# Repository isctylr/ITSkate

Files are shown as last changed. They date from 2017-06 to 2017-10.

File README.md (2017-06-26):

# ITSkate
The collection of hardware and software for my electric skateboard project.

The only portion currently available is the remote, which can be found in the "Remote" folder.
  - This includes the hardware for the remote (TX), joystick, and receiver (RX), plus software. More information available in the folder.

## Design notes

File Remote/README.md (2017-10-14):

# ITSkate Remote

An open source remote for the VESC based on the arduino samd architecture and the HM-10 BLE module.

To build the board from scratch will require the following items:
	- All 3 finished boards (A BOM is in the works, but can be determined from the EAGLE files under "Hardware").
	- The Arduino IDE with the Arduino SAMD boards installed.
	- The bootloader, which can be loaded by adding http://isaactaylor.net/package_itaylor_index.json to Preferences>Additional Boards Manager URLs, and installing ITSkate Remote from the Board Manager.
	- A j-link, stlink v2, or other programmer for the samd chip. (This guide will use the stlink v2).

## Building the board

## Programming the HM-10s

Programming the HM-10 module takes 6 steps, using the AT commands. You may choose to perform this step later, as the TX software includes an AT passthrough mode.

You can learn more about the HM-10 and it's AT commands from the manual: http://fab.cba.mit.edu/classes/863.15/doc/tutorials/programming/bluetooth/bluetooth40_en.pdf

1. AT
You should recieve OK in return. If nothing appears, make sure you have a genuine HM10 and not a clone, then make sure you are not sending LF or CR, and that your baud rate is 9600 (we will be changing this later, but this is the default).

2. AT+ADDR?
Take note of the address of both the RX and TX.

3. AT+ROLE?
Setting the role will depend on if this is the TX or RX. The TX will be set to AT+ROLE1, because it is the master device. The RX will be set to AT+ROLE0 (left as default).

4. AT+CONxxxxxxxx
Replace the xxxxx with the address of the opposite board, performing the command first on the RX board, then the TX. If both are powered on, you should recieve OK+CONN from the TX.

5. AT+POWE3
Boost the power on both to 6dbm.

6. AT+BAUD4
Set the baud rate of the UART connection to 115200. 

7. AT+RESET
After resetting you'll have to reconnect with the baud rate of 115200. You can type AT to check your work.

## Building the bootloader

## Flashing the bootloader

## Loading the software

Download VescUartControl library by RollingGecko Make sure to choose the
VESC6 branch if you program your vesc with vesc-tool and not bldc.
Add the following lines to VescUart.h:

#ifdef ARDUINO_ARCH_SAMD
#define SERIALIO Serial1  
#define DEBUGSERIAL Serial
#endif

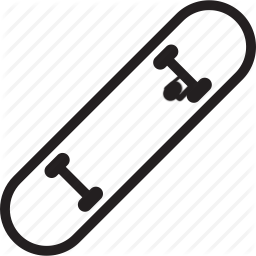
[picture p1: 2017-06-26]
Remote/hardware/skateboard-256.bmp

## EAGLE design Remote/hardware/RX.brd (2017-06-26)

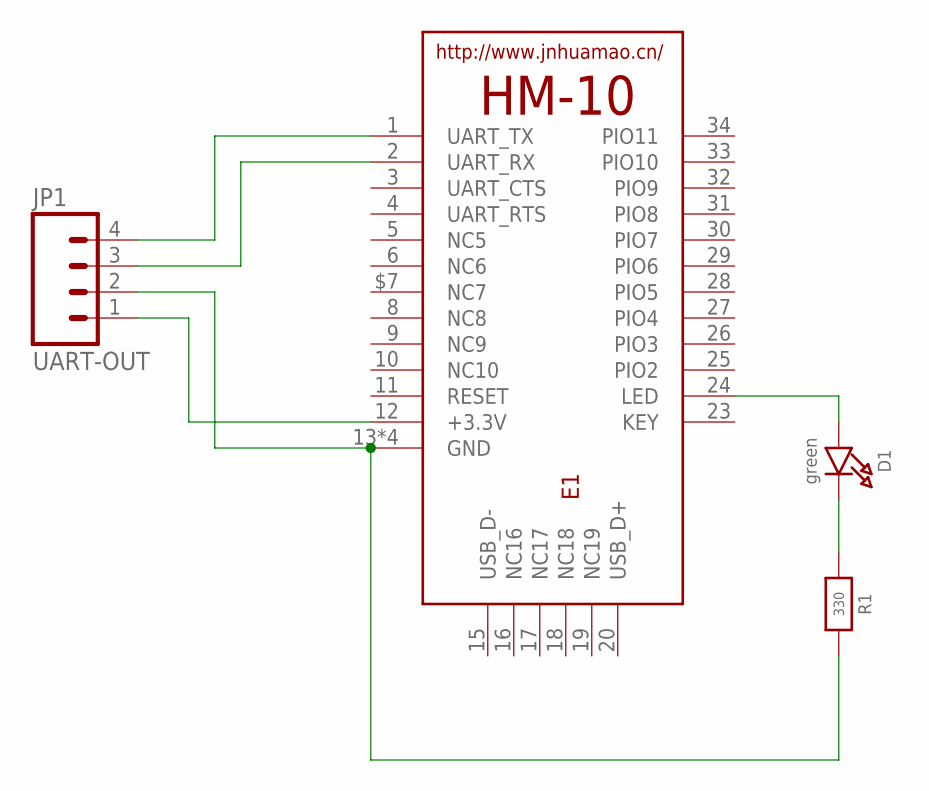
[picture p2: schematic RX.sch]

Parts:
D1: green; CHIPLED_0805_NOOUTLINE
E1: HM-10-BOARD; 26.9X13X2.2_BOARD
JP1: UART-OUT; 1X04
R1: 330; 0805-NO

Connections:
unnamed: E1.1 (UART_TX), JP1.4
unnamed: E1.2 (UART_RX), JP1.3
unnamed: E1.13 (GND), E1.14 (GND), E1.21 (GND), E1.22 (GND), JP1.2, R1.2
unnamed: E1.12 (+3.3V), JP1.1
unnamed: D1.A, E1.24 (LED)
unnamed: D1.C, R1.1

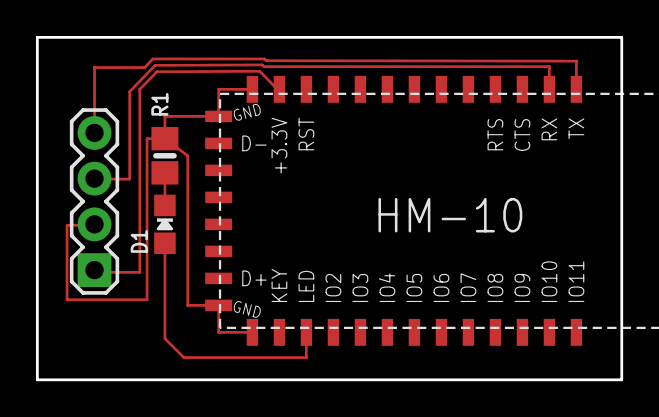
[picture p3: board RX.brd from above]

Board: 2 copper layers, 32.5 x 19.0 mm, 4 parts (0 on the bottom side), 6 nets.

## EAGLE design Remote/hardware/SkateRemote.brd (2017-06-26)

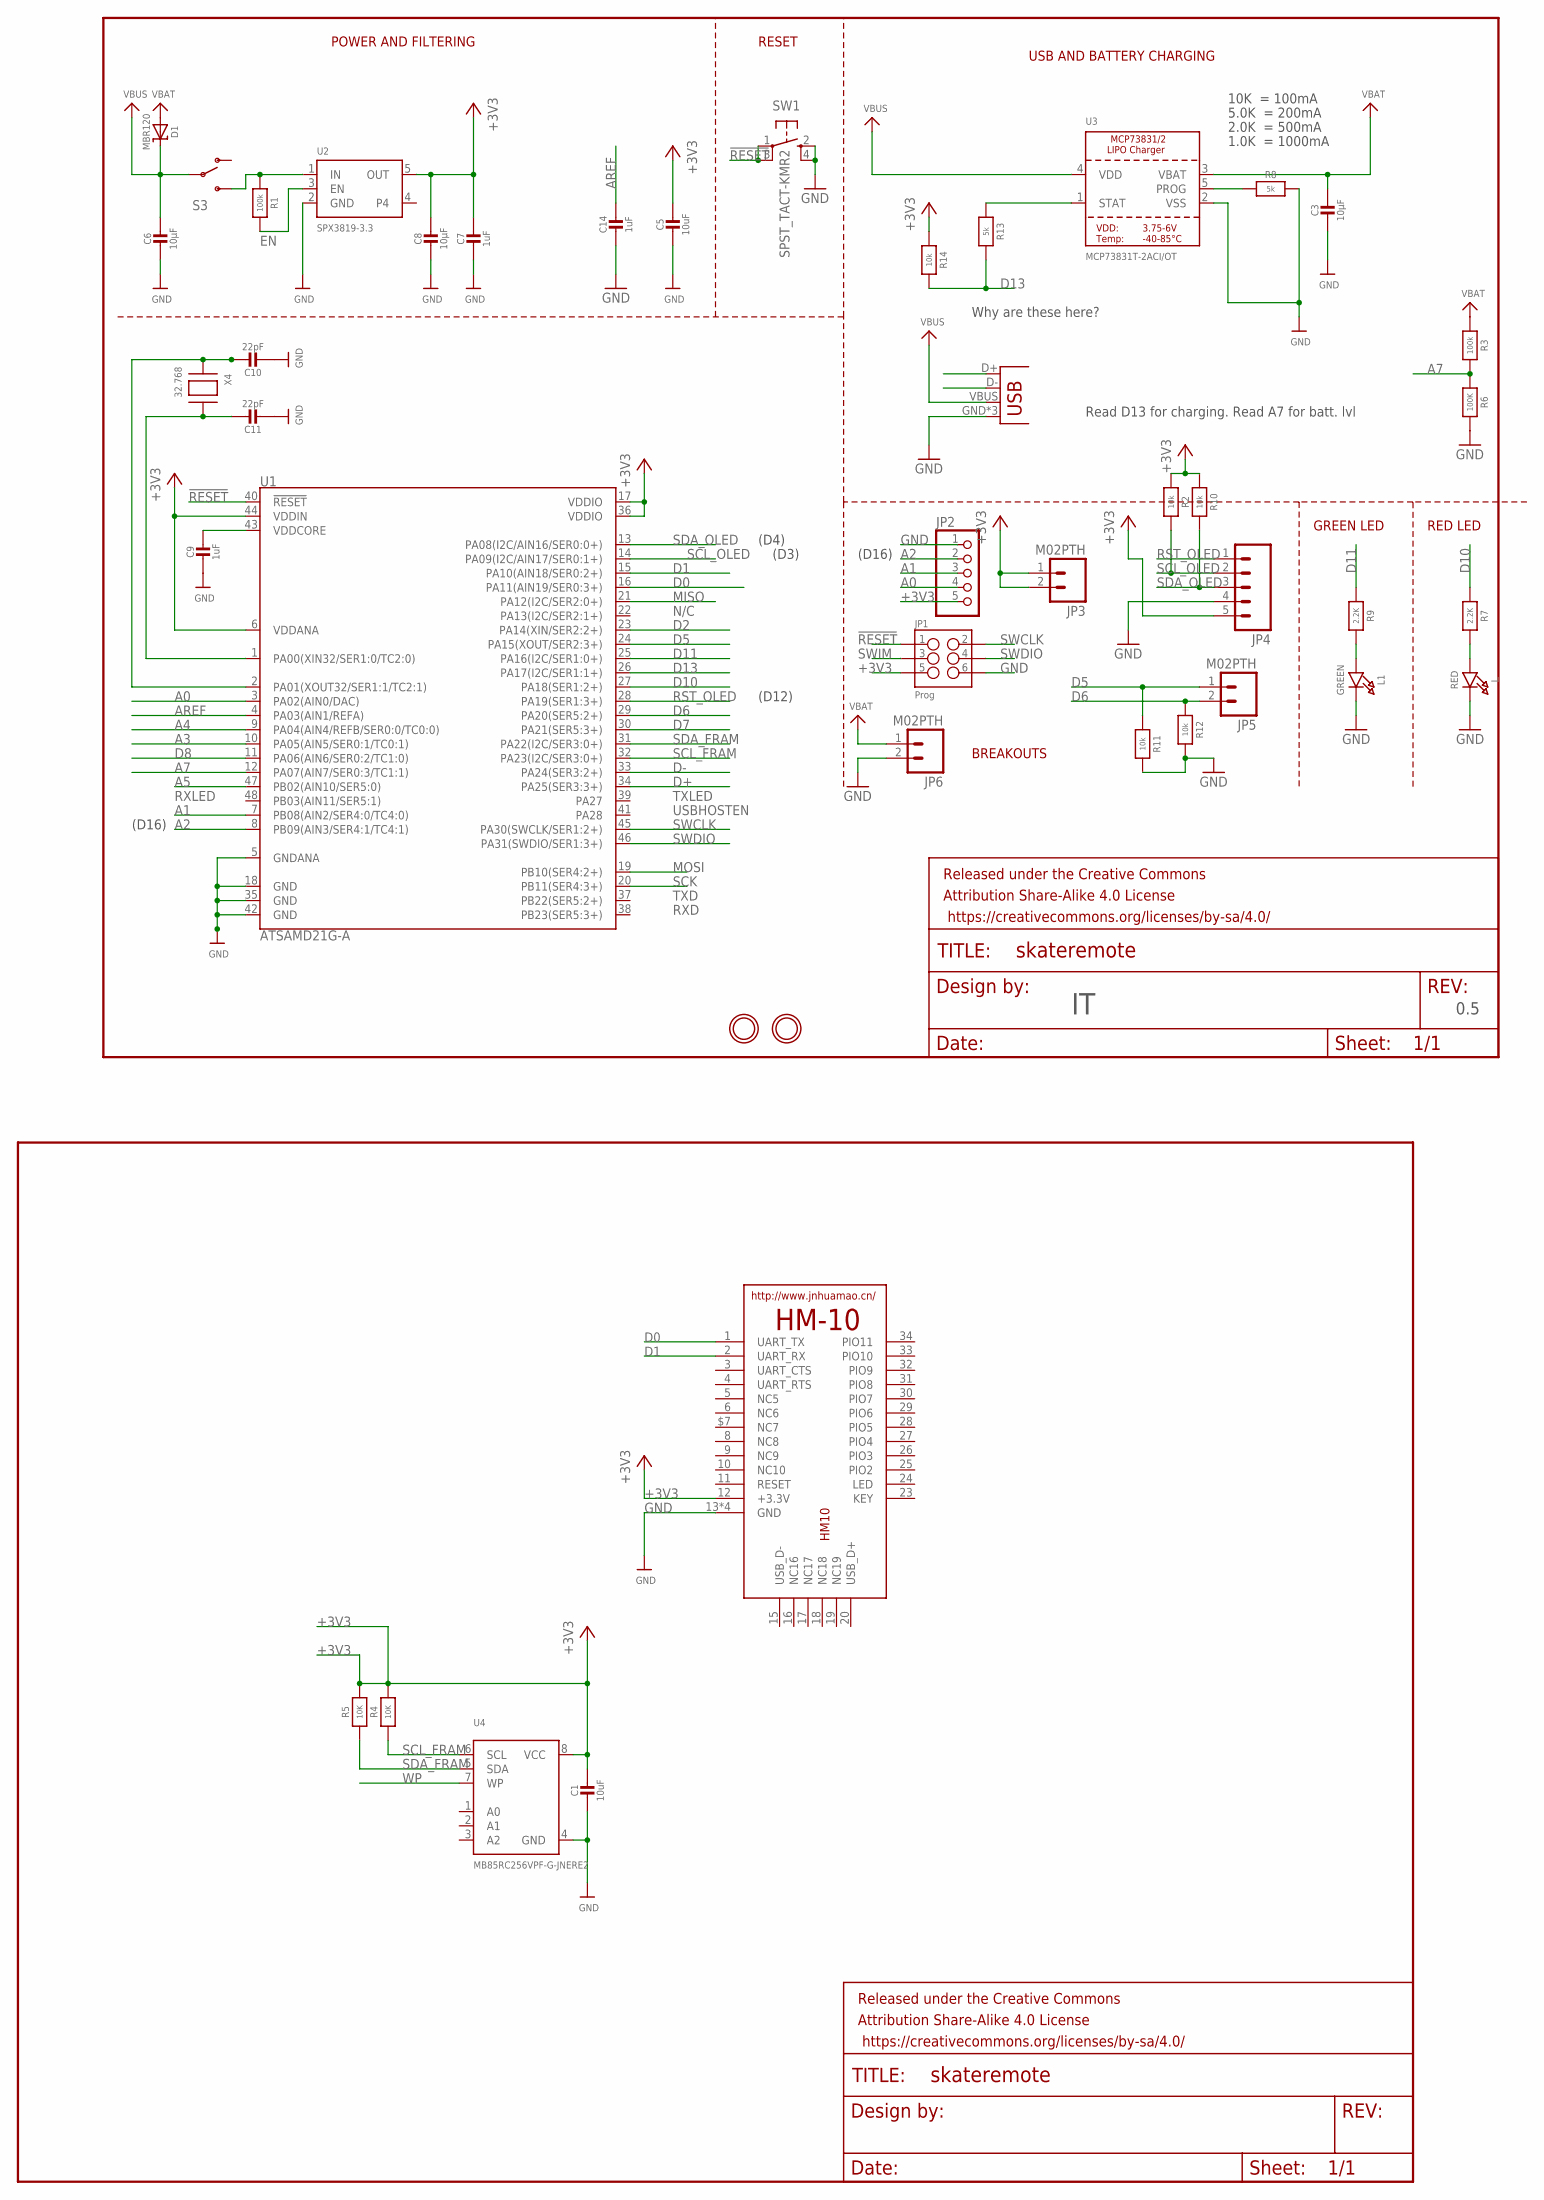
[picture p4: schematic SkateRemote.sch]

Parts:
C1: 10uF; _0805MP
C3, C6, C8: 10µF; 0805-NO
C5: 10uF; 0805-NO
C7, C9, C14: 1uF; 0805-NO
C10, C11: 22pF; 0805-NO
D1: MBR120; SOD-123
FRAME2, FRAME3: FRAME-LETTER; CREATIVE_COMMONS
HM10: HM-10-BOARD; 26.9X13X2.2_BOARD
JP1: Prog; 2X3
JP2: PINHD-1X5; 1X05
JP3, JP5, JP6: M02PTH; 1X02
JP4: M05PTH; 1X05
L: RED; CHIPLED_0805_NOOUTLINE
L1: GREEN; CHIPLED_0805_NOOUTLINE
R1, R3: 100k; 0805-NO
R2, R10, R11, R12, R14: 10k; 0805-NO
R4, R5: 10K; _0805MP
R6: 100K; 0805-NO
R7, R9: 2.2K; 0805-NO
R8, R13: 5k; 0805-NO
S3: SWITCH-SPDT-SMD-A; SWITCH-SPST-SMD-A
SW1: SPST_TACT-KMR2; KMR2
U1: ATSAMD21G-A; TQFP-48
U2: SPX3819-3.3; SOT23-5
U3: MCP73831T-2ACI/OT; SOT23-5
U4: MB85RC256VPF-G-JNERE2; SOIC8_208MIL
U$31, U$32: MOUNTINGHOLE2.5; MOUNTINGHOLE_2.5_PLATED
X3: microUSB; USB-MICROB
X4: 32.768; XTAL3215

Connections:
!RESET: JP1.1, SW1.1, SW1.3 (P1), U1.40 (!RESET!)
+3V3: C1.1, C5.1, C7.1, C8.1, HM10.12 (+3.3V), JP1.5, JP2.5, JP3.1, JP3.2, JP4.5, R2.1, R4.2, R5.2, R10.1, R14.1, U1.6 (VDDANA), U1.17 (VDDIO), U1.36 (VDDIO), U1.44 (VDDIN), U2.5 (OUT), U4.8 (VCC)
A0: JP2.4, U1.3 (PA02(AIN0/DAC))
A1: JP2.3, U1.7 (PB08(AIN2/SER4:0/TC4:0))
A2: JP2.2, U1.8 (PB09(AIN3/SER4:1/TC4:1))
A3: U1.10 (PA05(AIN5/SER0:1/TC0:1))
A4: U1.9 (PA04(AIN4/REFB/SER0:0/TC0:0))
A5: U1.47 (PB02(AIN10/SER5:0))
A7: R3.2, R6.1, U1.12 (PA07(AIN7/SER0:3/TC1:1))
AREF: C14.1, U1.4 (PA03(AIN1/REFA))
D0: HM10.1 (UART_TX), U1.16 (PA11(AIN19/SER0:3+))
D1: HM10.2 (UART_RX), U1.15 (PA10(AIN18/SER0:2+))
D2: U1.23 (PA14(XIN/SER2:2+))
D5: JP5.1, R11.1, U1.24 (PA15(XOUT/SER2:3+))
D6: JP5.2, R12.1, U1.29 (PA20(SER5:2+))
D7: U1.30 (PA21(SER5:3+))
D8: U1.11 (PA06(AIN6/SER0:2/TC1:0))
D10: R7.1, U1.27 (PA18(SER1:2+))
D11: R9.1, U1.25 (PA16(I2C/SER1:0+))
D13: R13.2, R14.2, U1.26 (PA17(I2C/SER1:1+))
D+: U1.34 (PA25(SER3:3+)), X3.D+
D-: U1.33 (PA24(SER3:2+)), X3.D-
EN: R1.2, U2.3 (EN)
GND: C1.2, C3.2, C5.2, C6.2, C7.2, C8.2, C9.2, C10.2, C11.2, C14.2, HM10.13 (GND), HM10.14 (GND), HM10.21 (GND), HM10.22 (GND), JP1.6, JP2.1, JP4.4, JP6.2, L.C, L1.C, R6.2, R8.2, R11.2, R12.2, SW1.2 (S), SW1.4 (S1), U1.5 (GNDANA), U1.18 (GND), U1.35 (GND), U1.42 (GND), U2.2 (GND), U3.2 (VSS), U4.4 (GND), X3.GND, X3.MT1 (GND), X3.MT2 (GND)
MISO: U1.21 (PA12(I2C/SER2:0+))
MOSI: U1.19 (PB10(SER4:2+))
unnamed: R13.1, U3.1 (STAT)
unnamed: L.A, R7.2
unnamed: R8.1, U3.5 (PROG)
unnamed: R1.1, S3.3 (S), U2.1 (IN)
unnamed: L1.A, R9.2
unnamed: C10.1, U1.2 (PA01(XOUT32/SER1:1/TC2:1)), X4.P$1
unnamed: C11.1, U1.1 (PA00(XIN32/SER1:0/TC2:0)), X4.P$2
RST_OLED: JP4.1, U1.28 (PA19(SER1:3+))
SCK: U1.20 (PB11(SER4:3+))
SCL_FRAM: R4.1, U1.32 (PA23(I2C/SER3:0+)), U4.6 (SCL)
SCL_OLED: JP4.2, R2.2, U1.14 (PA09(I2C/AIN17/SER0:1+))
SDA_FRAM: R5.1, U1.31 (PA22(I2C/SER3:0+)), U4.5 (SDA)
SDA_OLED: JP4.3, R10.2, U1.13 (PA08(I2C/AIN16/SER0:0+))
SWCLK: JP1.2, U1.45 (PA30(SWCLK/SER1:2+))
SWDIO: JP1.4, U1.46 (PA31(SWDIO/SER1:3+))
SWIM: JP1.3
VBAT: C3.1, D1.A, JP6.1, R3.1, U3.3 (VBAT)
VBUS: C6.1, D1.C, S3.2, U3.4 (VDD), X3.VBUS
VDDCORE: C9.1, U1.43 (VDDCORE)
WP: U4.7 (WP)

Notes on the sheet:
POWER AND FILTERING
RESET
10K = 100mA
5.0K = 200mA
2.0K = 500mA
1.0K = 1000mA
USB AND BATTERY CHARGING
BREAKOUTS
RED LED
RXLED
N/C
TXLED
USBHOSTEN
TXD
RXD
(D4)
(D3)
(D12)
(D16)
GREEN LED
Read D13 for charging. Read A7 for batt. lvl
Why are these here?
0.5

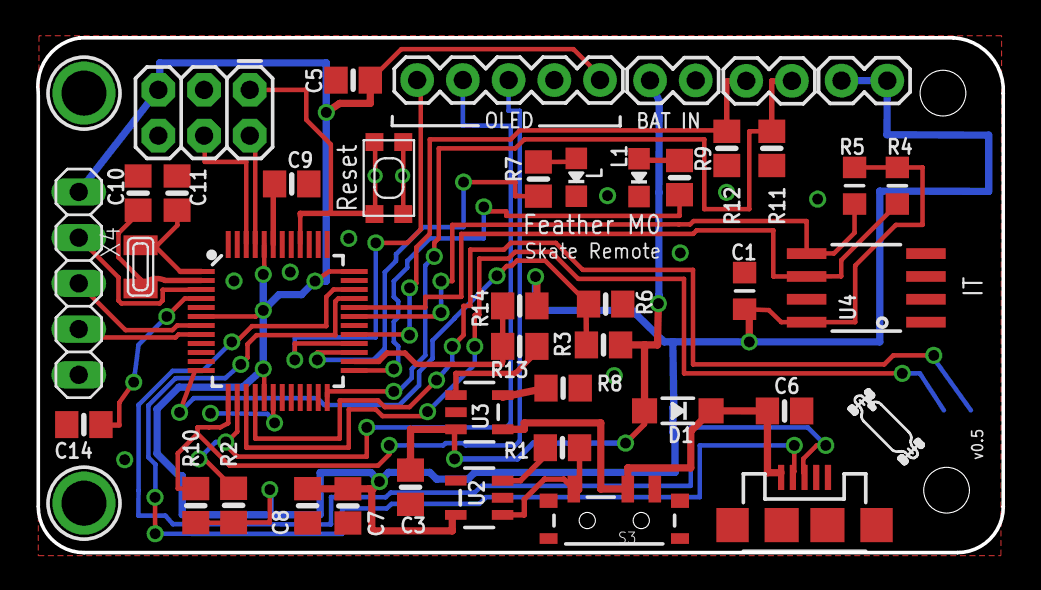
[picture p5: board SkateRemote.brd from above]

Board: 2 copper layers, 53.6 x 28.6 mm, 46 parts (1 on the bottom side), 35 nets.

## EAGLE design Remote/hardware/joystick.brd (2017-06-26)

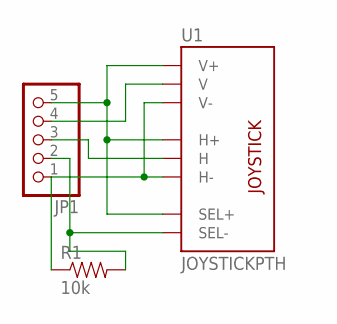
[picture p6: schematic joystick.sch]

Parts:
JP1: PINHD-1X5; 1X05
R1: 10k; 0805
U1: JOYSTICKPTH; JOYSTICK

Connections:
BTN: JP1.2, R1.2, U1.B2A (SEL-)
GND: JP1.1, R1.1, U1.H3 (H-), U1.V3 (V-)
VCC: JP1.5, U1.B1A (SEL+), U1.H1 (H+), U1.V1 (V+)
X: JP1.4, U1.V2 (V)
Y: JP1.3, U1.H2 (H)

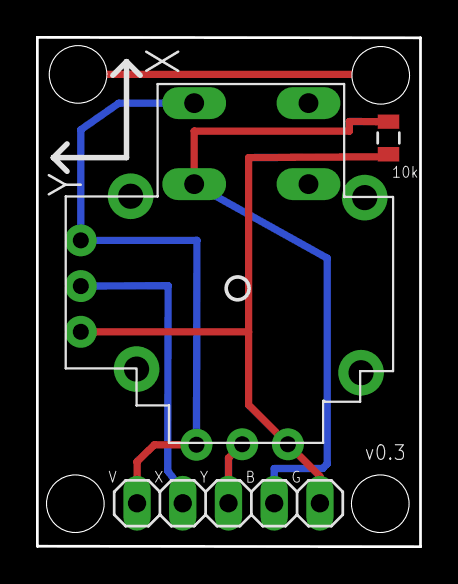
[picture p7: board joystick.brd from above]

Board: 2 copper layers, 21.3 x 28.3 mm, 3 parts (0 on the bottom side), 5 nets.

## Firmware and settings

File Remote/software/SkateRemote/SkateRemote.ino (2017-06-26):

/***************************************************************
*                         SkateRemote.ino
* 
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
* @author: Isaac Taylor
*
****************************************************************/

#include <Wire.h>
#include <Adafruit_GFX.h>
#include <Adafruit_SSD1306_newWire.h> //Uses a new TwoWire interface on pins 4,3
#include <Adafruit_FRAM_I2C.h>
#include "VescUart.h"
#include "datatypes.h"

// #define DEBUG

// #define OLED

//// BEGIN oled config
#ifdef OLED

#define RESET_OLED 12
Adafruit_SSD1306_newWire oled(RESET_OLED);

#endif
//// END oled config

// BEGIN fram config
Adafruit_FRAM_I2C fram = Adafruit_FRAM_I2C();
uint16_t framAddr = 0;
// END fram config


// BEGIN ble config
#define B_RX 0
#define B_TX 1
#define BLE_BAUD 115200

#define ble Serial1
//SoftwareSerial ble(B_RX, B_TX); // RX, TX  
// No SoftwareSerial since feather has a hardware Serial available!
// END ble config

// BEGIN joystick config
// The joystick has "360 degrees" plus a button when pushed down
#define P_UD A7 
#define P_LR A1
#define P_B 16

// Only up and down need to be very accurate, l/r is just for menu nav

// END joystick config

// BEGIN lipo config
#define VBATPIN A0
#define CHARGING 13
float tx_bat;
bool charging = false;
//END lipo config

// BEGIN vesc communication
#define DIA_WHEEL  76 //mm
#define RATIO_GEAR  2 //TODO: Maybe configure these in remote?

#define C_BTN 5
#define Z_BTN 6

remotePackage remPack;
struct bldcMeasure VescMeasuredValues;

float speed = 0;
float distanceTravel = 0;

int fcount = 0;

const float ratioRpmSpeed = ((DIA_WHEEL * 3.14156) / RATIO_GEAR) * 60 / 1000000; //RPM to Km/h
const float  rationRotDist = ((DIA_WHEEL * 3.14156) / RATIO_GEAR) / 1000000; //RPM to travelled km
// END vesc communication

// BEGIN lights
#define R_LED 10
#define G_LED 11
bool rled = false, gled = false;
// END lights

// BEGIN MODES
typedef enum
{
  LOAD = 0,
  RUN = 1,
  MENU = 2,
  
  ERR = 3,
  BLE_PROG = 4 // Enter by ??, exit by sending '|~'
} MODES;
 
MODES mode = RUN;
MODES prevMode;

String errcode = "";
//END MODES

// BEGIN variables
short mScreen, p_mScreen, mPoint, p_mPoint;
short debouncing = 0;
int flasht = 0;

bool expert = false; // fram: 0x1
bool metric = false; //       0x2
short up = 0, down = 0; //    0x3, 0x4
int center = 512; //          0x5
int vescCells = 10; //        0x6

bool gfram; //                 Not stored in mem. Triggers if fram fails.
// END variables

void setup() {

  pinMode(R_LED, OUTPUT);
  pinMode(G_LED, OUTPUT);
  digitalWrite(R_LED, HIGH);
  digitalWrite(G_LED, HIGH);
  gled=rled=true;

  pinMode(CHARGING, INPUT);

#ifdef DEBUG
  while (!Serial);
#endif
  Serial.begin(9600);

#ifdef OLED
  oled.begin(SSD1306_SWITCHCAPVCC, SSD1306_I2C_ADDRESS);
  draw_init();
#endif



  ble.begin(BLE_BAUD);

  pinMode(P_B, INPUT);
  pinMode(C_BTN, INPUT);
  pinMode(Z_BTN, INPUT);

  if (fram.begin()) {  // you can stick the new i2c addr in here, e.g. begin(0x51);
#ifdef DEBUG    
    Serial.println("Found I2C FRAM");
#endif
    gfram = true;
  } else {
#ifdef DEBUG
    Serial.println("No I2C FRAM found ... check your connections\r\n");
#endif
    gfram = false;
    mode = ERR;
    errcode = "FRam connection failed";
  }
  
  if (gfram) {
    if(fram.read8(0x0) != 0x1) {
#ifdef DEBUG
      Serial.println("First time setup. Writing default values to fram");
#endif
      fram.write8(0x0, 0x1);
      fram.write8(0x1, expert); 
      fram.write8(0x2, metric);
      fram.write8(0x3, up);
      fram.write8(0x4, down);
      fram.write8(0x5, center);
      fram.write8(0x6, vescCells);
    } else {
      expert = fram.read8(0x1);
      metric = fram.read8(0x2);
      up = fram.read8(0x3);
      down = fram.read8(0x4);
      center = fram.read8(0x5);
      vescCells = fram.read8(0x6);
#ifdef DEBUG
      Serial.println("Reading values from memory... ");
      Serial.print("Expert mode: ");
        Serial.println(expert);
      Serial.print("Metric? ");
        Serial.println(metric);
      Serial.print("Calibration values: ");
        Serial.print(up); Serial.print(" "); Serial.print(center);
        Serial.print(" "); Serial.println(down);
      Serial.print("Vesc battery size: ");
        Serial.println(vescCells);
#endif
    }
  }
  digitalWrite(G_LED, gled=false);
  digitalWrite(R_LED, rled=false);
}

void loop() {

charging = !digitalRead(CHARGING);

if (charging) {
  if (flasht > 10) {
    digitalWrite(G_LED, gled=!gled);
    flasht = 0;
  }
  flasht++;
} else {
//  ana
}
  
  if (mode == ERR) {
    Serial.println(errcode);
    digitalWrite(G_LED, gled=false);
    digitalWrite(R_LED, rled=!rled);

#ifdef OLED
    draw_err();
#endif
    delay(1000);

  } else if (mode == BLE_PROG) {

    char c, p;
    if (Serial.available()) {
      p = c;
      c = Serial.read();
      if(p == '|' && c == '~') {
        mode = RUN;
      } else {
        Serial1.print(c);
      }
    }

    if (Serial1.available()) {
      c = Serial1.read();
      Serial.print(c);    
    }

  } else if (mode == RUN) {
//    oled.clearDisplay();
    /*
     * Speed
     * Vesc battery
     * Remote Battery
     * Distance Travelled
     * Beginner/Expert Mode
     */

    // TODO: Calibration values included for P_UD
    remPack.valXJoy = map(analogRead(P_LR), 0, 1023, 255, 0);
    remPack.valYJoy = map(analogRead(P_UD), 0, 1023, 0, 255);
    remPack.valLowerButton = LOW; // C & Z... Not implemented
    remPack.valUpperButton = digitalRead(P_B);
    
    VescUartSetNunchukValues(remPack);
/*
    while(ble.available()) {

        VescMeasuredValues.avgMotorCurrent = ble.parseFloat();
        VescMeasuredValues.avgInputCurrent = ble.parseFloat();
        VescMeasuredValues.dutyCycleNow = ble.parseFloat();
        VescMeasuredValues.rpm = ble.parseInt();
        VescMeasuredValues.inpVoltage = ble.parseFloat();
        VescMeasuredValues.ampHours = ble.parseFloat();
        VescMeasuredValues.ampHoursCharged = ble.parseFloat();
        VescMeasuredValues.tachometer = ble.parseInt();
        VescMeasuredValues.tachometerAbs = ble.parseInt();        
    }
    */

    if (VescUartGetValue(VescMeasuredValues)) {
#ifdef DEBUG
        SerialPrint(VescMeasuredValues);
#endif
        if (!charging) digitalWrite(G_LED, gled=true);
        digitalWrite(R_LED, rled=false); // TODO: battery?
        fcount = 0;
    }
    else
    {
#ifdef DEBUG
      Serial.println("Failed to get data from UART!");
#endif // DEBUG
      if (fcount >= 10) {
        digitalWrite(R_LED, rled=true);
        if (!charging) digitalWrite(G_LED, gled=false);
      }
      fcount++;
    }

    tx_bat = analogRead(VBATPIN);
    //tx_bat *= 3.3;
    //tx_bat /= 128; //TODO: this gives voltage but feels lossy for percentage
    //tx_bat = map(tx_bat, 3.2, 4.2, 0, 100); // Let's get percent, yeah?
    tx_bat = map(tx_bat, 0, 1023, 0, 100);
    speed = VescMeasuredValues.rpm * ratioRpmSpeed;
    distanceTravel = VescMeasuredValues.tachometer * rationRotDist;

#ifdef DEBUG
    Serial.print("Battery percent: ");
    Serial.print(tx_bat); Serial.print(" Joystick: ");
    Serial.print(remPack.valXJoy); Serial.print(" ");
    Serial.println(remPack.valYJoy);
    Serial.print("C: "); Serial.println(remPack.valUpperButton);
    Serial.print("Z: "); Serial.println(remPack.valLowerButton);
    delay(50); //TODO
#endif

    delay(10);
  } else if (mode == LOAD && prevMode != mode) {
    prevMode = mode;
#ifdef OLED
    draw_load();
#endif
  } else if (mode == MENU) {
    // First time in the menu, 
    if (prevMode != MENU) {
      if (expert) {
        mScreen = 10;
        mPoint = 0;
      } else {
        mScreen = mPoint = 0;
      }
      p_mScreen = p_mPoint = 100; // Why not? Just not 0.
      prevMode = MENU;
    }
    if ((mScreen != p_mScreen) || (mPoint != p_mPoint)) {
      p_mScreen = mScreen;
      p_mPoint = mPoint;
#ifdef OLED
      draw_menu(mScreen, mPoint);
#endif      
    }
    
    if (debouncing > 90) {
      if (analogRead(P_LR) >= 950) {
        if (mPoint < 4) 
          mPoint++;
        debouncing = 0;
      } else if (analogRead(P_LR) <= 100) {
        if (mPoint > 0)
          mPoint--;
        debouncing = 0;
      } else if (digitalRead(P_B) == HIGH) {
        mScreen = mScreen + mPoint + 10;
        // Beginner/expert mode...
        if (mScreen == 10) expert = true;
        if (mScreen == 20) {
          mScreen = 0; 
          expert = false;
        }
        debouncing = 0;
      }
    }
  }
  debouncing++;
  if(debouncing >= 250) debouncing = 91;
}

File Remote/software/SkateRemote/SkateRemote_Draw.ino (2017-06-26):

#line 2

//#include <Arduino.h>

#ifdef OLED

String menuItems[4];

void draw_init() {
  //oled.display();
  //oled.setTextSize(1);
  //oled.setTextColor(WHITE);

}

void draw_load() {
  
}
/*
* MENU 
* - (0) Beginner mode (S0) / Expert Mode (S10)
* - (1) Calibrate Throttle -> (S11)
* - (2) Unit types -> (S12) : km/h vs. mph
* - (3) Exit and Save
*/

void draw_menu(int screen, int point) {
  switch(screen) {
    case 0:
    {
      menuItems[0] = "Beginner Mode";
      menuItems[1] = "Calibrate Throttle";
      menuItems[2] = "Unit Types";
      menuItems[3] = "Exit and Save";
      break;
    }
    case 10:
    {
      menuItems[0] = "Expert Mode";
      menuItems[1] = "Calibrate Throttle";
      menuItems[2] = "Unit Types";
      menuItems[3] = "Exit and Save";
      break;
    }
    case 11:
      // Throttle Calibration
      break;
    case 12:
      // Units options
      if (metric) menuItems[0] = "km/hr";
      else menuItems[0] = "mi/hr";
      menuItems[1] = "Back";
      menuItems[2] = menuItems[3] = "";
      break;
  }
  for (int i=0; i<4; i++) {
    oled.setCursor(10, 10+ i*15);
    if (i == mPoint) oled.print(">");
    oled.setCursor(15, 10+ i*15);
    oled.print(menuItems[i]);
  }
}

void draw_err() {
  
}

#endif

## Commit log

2017-06-26 First Upload
    [RX.brd, RX.sch, SkateRemote.brd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]
2017-10-14 Added some to the readme before I forget. Added a zip with the working UART Library for VESC6.

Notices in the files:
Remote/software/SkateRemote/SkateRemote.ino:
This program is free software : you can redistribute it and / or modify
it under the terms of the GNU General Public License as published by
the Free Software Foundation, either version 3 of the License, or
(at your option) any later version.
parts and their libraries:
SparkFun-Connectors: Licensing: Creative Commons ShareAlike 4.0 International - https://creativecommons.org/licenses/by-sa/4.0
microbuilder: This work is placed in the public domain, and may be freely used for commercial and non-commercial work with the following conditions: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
